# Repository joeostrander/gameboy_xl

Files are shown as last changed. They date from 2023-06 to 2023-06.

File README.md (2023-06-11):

# Gameboy_XL & Gameboy_XL Touch

## Description
A larger, grown-up Gameboy... but it's not a GameMan

2 versions you can make, 1 with a touch screen!

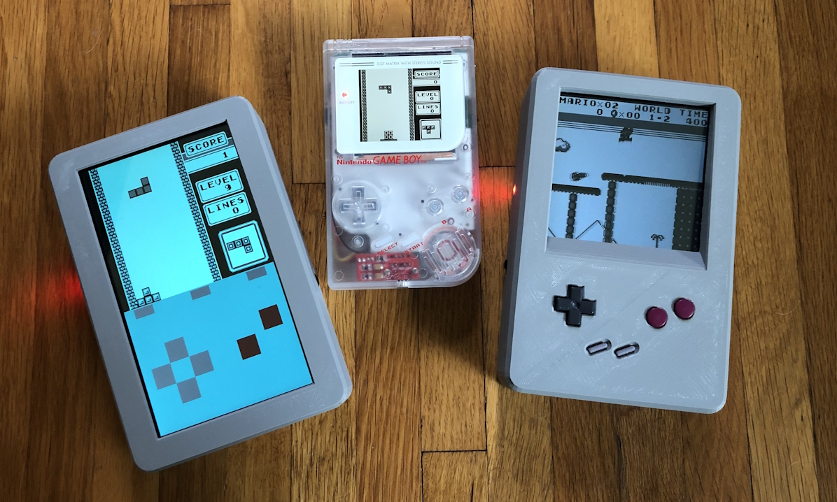
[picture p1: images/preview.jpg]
preview


[Video](https://youtu.be/DkDZt74SX64)

See also:

Gameboy consolizer that me and Andy West collaborated on:
https://github.com/joeostrander/consolized-game-boy

PICO LCD
https://github.com/joeostrander/PICO_LCD

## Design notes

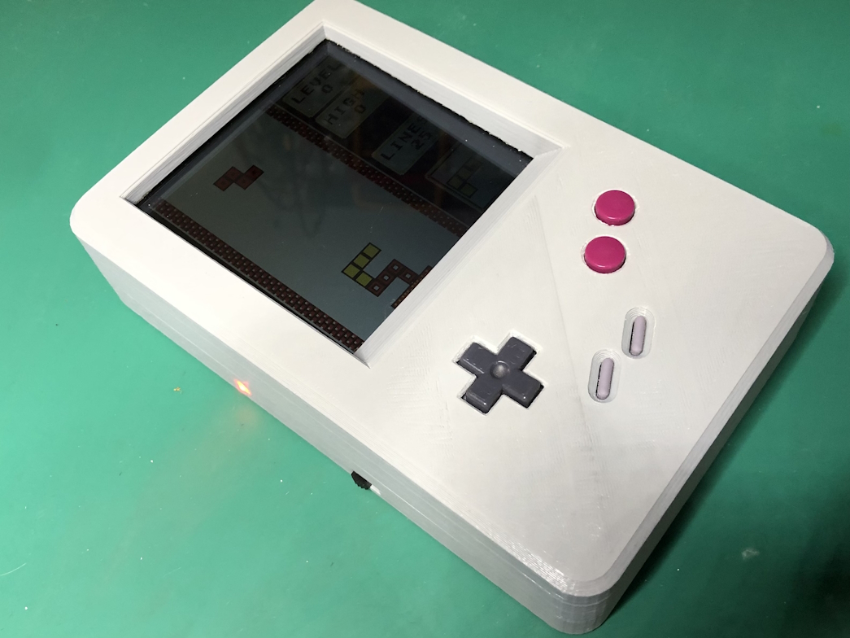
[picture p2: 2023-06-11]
images/IMG_E4839.JPG

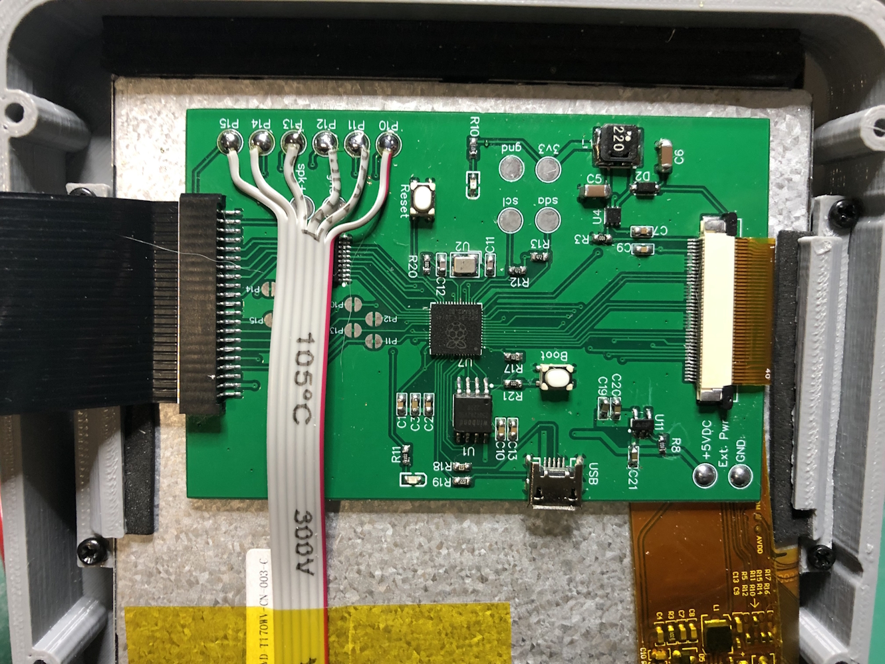
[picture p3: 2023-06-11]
images/IMG_E4575.JPG

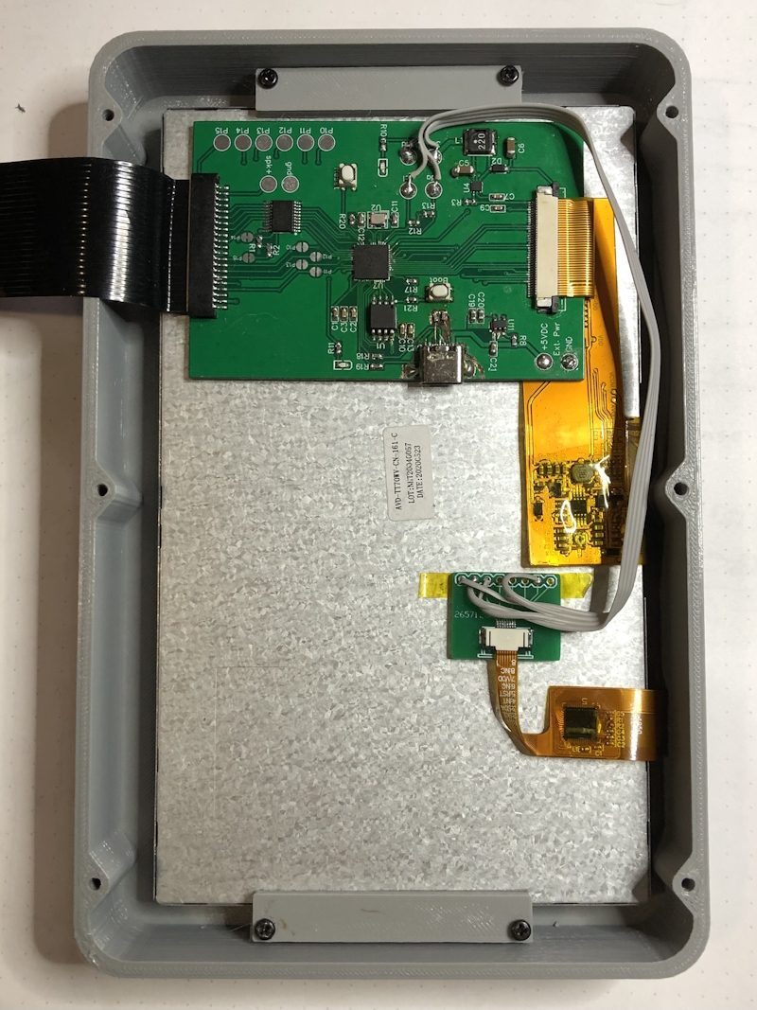
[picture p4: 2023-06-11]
images/touch_lcd_back1.JPG

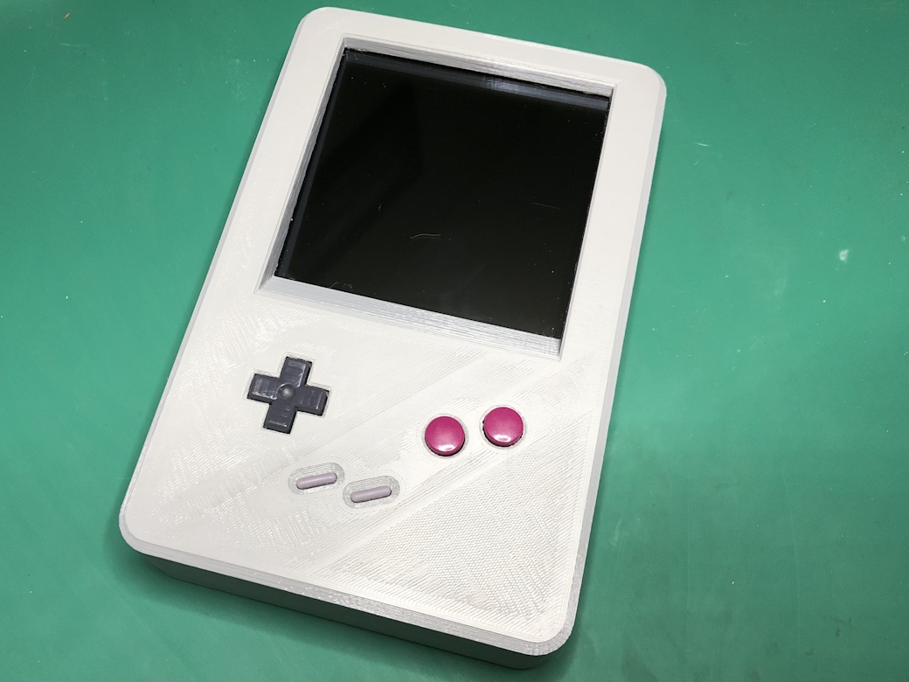
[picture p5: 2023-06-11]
images/IMG_E4836.JPG

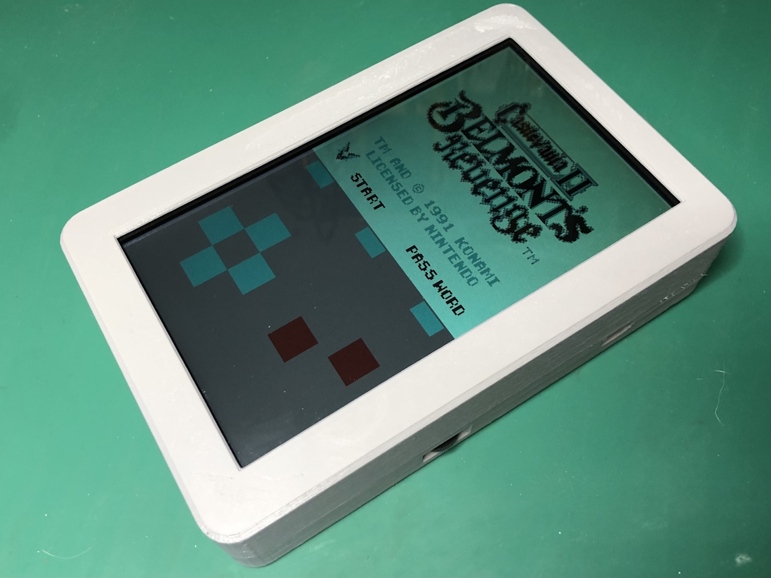
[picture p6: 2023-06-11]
images/touch2.JPG

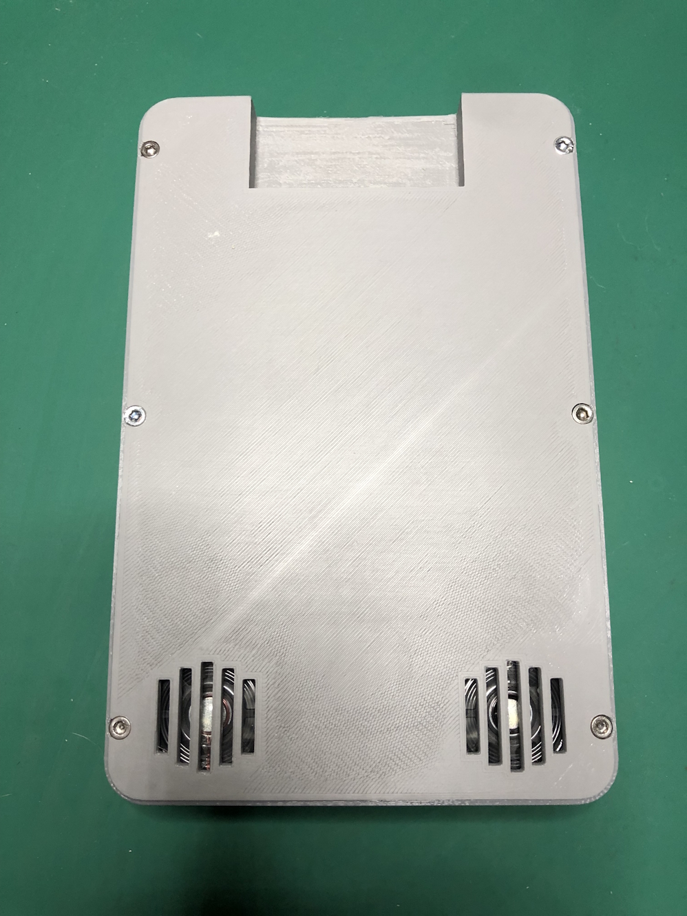
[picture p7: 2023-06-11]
images/touch_case_back.JPG

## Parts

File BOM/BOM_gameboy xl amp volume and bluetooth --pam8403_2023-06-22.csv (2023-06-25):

ID | Name | Designator | Footprint | Quantity | Manufacturer Part | Manufacturer | Supplier | Supplier Part
1 | 0.47uF | C1,C2 | 0603 CAPACITOR | 2 | CAPCERAMIC0.22UF16V20%X5R0201 | null
2 | 0.1uF | C3 | 0603 CAPACITOR | 1 | CAPCERAMIC0.22UF16V20%X5R0201 | null
3 | 10uF | C4 | 0603 CAPACITOR | 1 | CAPCERAMIC0.22UF16V20%X5R0201 | null
4 | 100uF 10V | C5 | CAP-SMD_L3.5-W2.8-R-RD | 1 | T491M107K006AT | KEMET | Digi-Key | 399-11391
5 | LED_BLUE | LED_BLUE | LED_5MM | 1
6 | 20K | R1,R2 | RESISTOR_R0603 | 2
7 | 10R | R3 | RESISTOR_R0603 | 1
8 | 1K | R4 | RESISTOR_R0603 | 1
9 | Button-6x6x9-Right-Angle | SW1 | SW-TH_BBJ | 1 | TL1105RF160Q94VO | E-Switch | Digi-Key | TL1105RF160Q94VO-ND
10 | EG1206A | SW2 | SW-TH_EG1206A | 1 | EG1206A | E-Switch | LCSC | C273392
11 | PAM8403DR_C348830 | U2 | SOP-16_L9.9-W3.9-P1.27-LS6.0-BL | 1 | PAM8403DR-H |  | Digi-Key | PAM8403DR
12 | KCX_BT_EMITTER | U3 | KCX_BT_EMITTER | 1 |  |  | Ali-Express
13 | DMG Volume potentiometer | VR1 | DMG-POT | 1 |  |  | Ali-Express

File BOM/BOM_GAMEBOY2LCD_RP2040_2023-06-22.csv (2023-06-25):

ID | Name | Designator | Footprint | Quantity | Manufacturer Part | Manufacturer | Supplier | Supplier Part
2 | 0.1uF | C1,C2,C7,C9,C13 | 0603 CAPACITOR | 5
3 | 2.2uF | C3,C10 | 0603 CAPACITOR | 2
4 | 10uF | C5,C6 | CAPC3216X180N | 2
5 | 15pF | C11,C12 | 0603 CAPACITOR | 2
6 | 10uF | C19,C20,C21 | 0603 CAPACITOR | 3
7 | MBR0540T1G | D2 | SOD-123_L2.8-W1.8-LS3.7-RD | 1 | MBR0540T1G | ON | LCSC | C21353
9 | 0541044031 V2 | J1 | 541044031 | 1
10 | 22uH | L1 | IND-SMD_L5.0-W5.0_VLCF5020 | 1 | VLCF5020T-220MR75-1 | TDK | LCSC | C87576
11 | TJ-S1608SW6TGLC6B-A5 | LED_BLUE1 | LED0603-R-RD_BLUE | 1 | TJ-S1608SW6TGLC6B-A5 | TOGIALED | LCSC | C192317
12 | TJ-S1608SW6TGLC2R-A5 | LED_RED1 | LED0603-R-RD_RED | 1 | TJ-S1608SW6TGLC2R-A5 | TOGIALED | LCSC | C192315
19 | 10K | R1,R2,R8,R17 | RESISTOR_R0603 | 4
20 | 10R | R3 | RESISTOR_R0603 | 1
21 | 470 | R10 | RESISTOR_R0603 | 1
22 | 1K | R11,R20,R21 | RESISTOR_R0603 | 3
23 | 4.7K | R12,R13 | RESISTOR_R0603 | 2
24 | 27R | R18,R19 | RESISTOR_R0603 | 2
37 | Boot | SW1 | PUSHBUTTON SMD 3X4X2.5 | 1
38 | Reset | SW2 | PUSHBUTTON SMD 3X4X2.5 | 1
39 | W25Q128JVSIQ | U1 | SOIC-8_L5.3-W5.3-P1.27-LS8.0-BL | 1 | W25Q128JVSIQ | WINBOND(??) | LCSC | C113767
40 | FA-238V 12.0000MA-C5 | U2 | CRYSTAL-SMD_4P-L3.2-W2.5-BL | 1 | FA-238V 12.0000MA-C5 | EPSON | LCSC | C1985398
41 | SN74LVC245APWR | U3 | TSSOP-20_L6.5-W4.4-P0.65-LS6.4-BL | 1 | SN74LVC245APWR | TI(Texas Instruments) | LCSC | C7848
42 | TPS61160DRVR | U4 | WSON-6_L2.0-W2.0-P0.65-TL-EP | 1 | TPS61160DRVR | TI(Texas Instruments) | LCSC | C165143
43 | DMG SCREEN CONNECTOR - NO HOLES | U6 | DMG SCREEN CONNECTOR - NO HOLES | 1 |  |  | Ali-Express
44 | RP2040 | U7 | RP2040-QFN56 | 1 | RP2040 | Raspberry Pi |  | C2961140
45 | AP2112K-3.3TRG1 | U11 | SOT-25-5_L3.0-W1.8-P0.95-LS3.0-BR | 1 | AP2112K-3.3TRG1 | DIODES | LCSC | C51118
46 | U-F-M5DD-W-2 | USB | MICRO-USB-SMD_MICRO-USB-A17 | 1 | U-F-M5DD-W-2 | HRO | LCSC | C145793

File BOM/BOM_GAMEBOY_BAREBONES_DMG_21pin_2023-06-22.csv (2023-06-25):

ID | Name | Designator | Footprint | Quantity | Manufacturer Part | Manufacturer | Supplier | Supplier Part
1 | 27pF | C1,C2 | 0603/SMD | 2
2 | 1uF | C3,C4 | CAP-SMD_L3.5-W2.8-R-RD | 2 | T491B105K050AT | KEMET | LCSC | C600503
3 | 1M | R13 | RESISTOR_R0603 | 1
4 | 180K | R14 | RESISTOR_R0603 | 1
5 | 510R | R16,R17 | RESISTOR_R0603 | 2
6 | dmg screen connector | U1 | DMG SCREEN CONNECTOR - NO HOLES | 1 |  |  | Ali-Express
7 | LH5264 Work RAM | U2 | DMG LH5264 | 1 |  |  | Get from a DMG or Super Gameboy cartridge
8 | DMG Cartridge Header PTH | U3 | DMG CARTRIDGE HEADER | 1 |  |  | Get from a DMG
9 | LH5264 Video RAM | U5 | DMG LH5264 | 1 |  |  | Get from a DMG or Super Gameboy cartridge
10 | DMG-CPU-B | U8 | DMG-CPU-B | 1 |  |  | Get from a DMG or Super Gameboy cartridge
11 | ABLS-4.194304MHZ-D-4-Y-T | X2 | CRYSTAL-SMD_L11.4-W4.7-LS12.7 | 1 | ABLS-4.194304MHZ-D-4-Y-T | ABRACON | Digi-Key | 535-14925

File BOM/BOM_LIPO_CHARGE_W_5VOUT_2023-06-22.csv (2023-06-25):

ID | Name | Designator | Footprint | Quantity | Manufacturer Part | Manufacturer | Supplier | Supplier Part
2 | 0.1uF | C4 | 0603 CAPACITOR | 1
3 | 10uF | C8,C14,C18,C21 | 0603 CAPACITOR | 4
4 | 22uF | C15,C16,C17 | CAPACITOR_SMD0805 | 3
5 | 10uF | C22,C23 | CAPACITOR_SMD0805 | 2
6 | S2B-PH-SM4-TB(LF)(SN) | CN1 | CONN-SMD_P2.00_S2B-PH-SM4-TB-LF-SN | 1 | S2B-PH-SM4-TB(LF)(SN) | JST | LCSC | C295747
7 | BAT20JFILM | D3 | SOD-323_L1.8-W1.3-LS2.5-RD | 1 | BAT20JFILM | ST(STMicroelectronics) | LCSC | C155590
10 | 1.5uH | L2 | IND-SMD_L4.0-W4.0 | 1 | XEL4030-152MEC | Coilcraft | Mouser | 994-XEL4030-152MEC
11 | SI2305B-TP | Q2 | SOT-23-3_L2.9-W1.3-P1.90-LS2.4-BR | 1 | SI2305B-TP | MCC(Micro Commercial Components) | LCSC | C668997
12 | 2K | R4 | RESISTOR_R0603 | 1
13 | 10K | R5,R6,R9 | RESISTOR_R0603 | 3
14 | 100K | R7 | RESISTOR_R0603 | 1
15 | TPS630701RNMR | U5 | TPS630701RNMR | 1 | TPS630701RNMR | Texas Instruments | Digi-Key | 296-47298
16 | MCP73831T-2ACI/OT | U8 | SOT-23-5_L3.0-W1.7-P0.95-LS2.8-BR | 1 | MCP73831T-2ACI/OT | MICROCHIP | LCSC | C424093
17 | Led 0603 | U9 | LED 0603 | 1

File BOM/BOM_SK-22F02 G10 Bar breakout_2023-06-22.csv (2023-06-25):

ID | Name | Designator | Footprint | Quantity | Manufacturer Part | Manufacturer | Supplier | Supplier Part | Price
1 | SK-22F02 G10 Bar | SW1 | SK-22F02 G10 BAR | 1 |  |  | Ali-Express
2 | HEADER_2.54_1X3 | U5 | HEADER_2.54_1X3 | 1

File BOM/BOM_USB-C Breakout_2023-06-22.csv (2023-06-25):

ID | Name | Designator | Footprint | Quantity | Manufacturer Part | Manufacturer | Supplier | Supplier Part | Price
1 | 5.1K | R1,R2 | RESISTOR_R0603 | 2
2 | HEADER_2.54_1X4 | U1 | HEADER_2.54_1X4 | 1
3 | USB_C RECEPTACLE - ADAFRUIT | X1 | USB_C_ADAFRUIT_4458 | 1

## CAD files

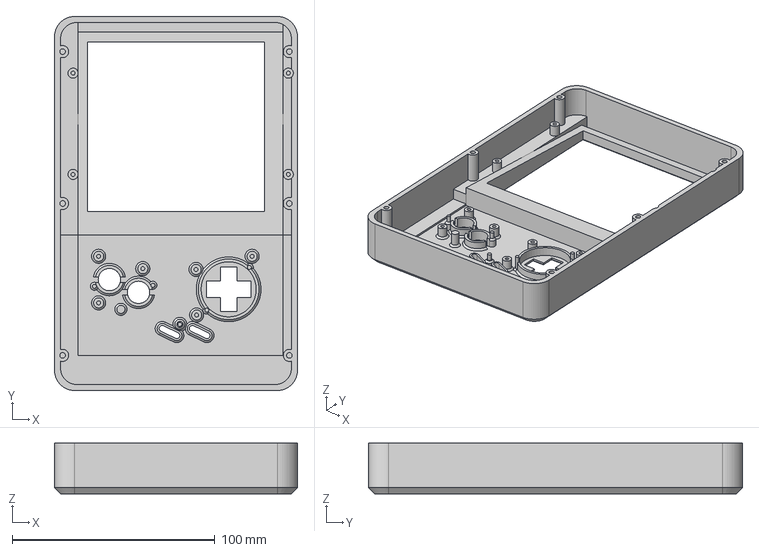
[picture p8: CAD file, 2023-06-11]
3D/non-touch/gameboy_xl_case_top.step
120.0 x 184.7 x 25.0 mm

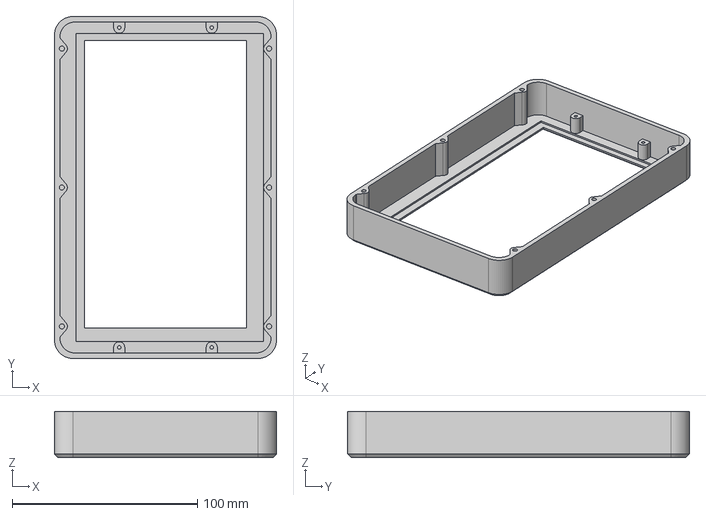
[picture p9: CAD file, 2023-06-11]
3D/touch/gameboy_xl_touch_case_top.step
120.0 x 184.8 x 25.0 mm

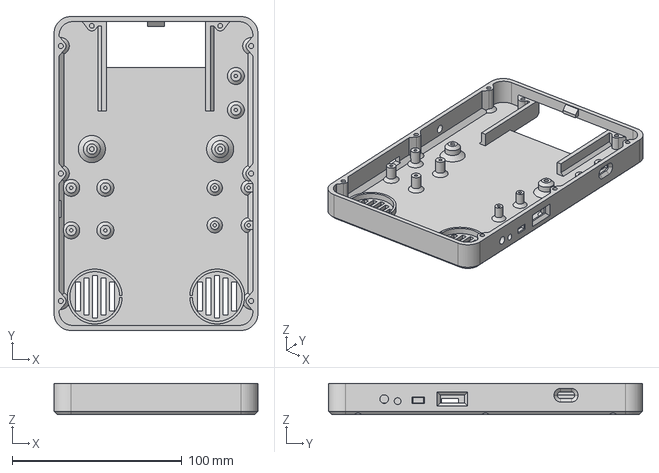
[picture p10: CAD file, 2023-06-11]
3D/non-touch/gameboy_xl_case_bottom.step
120.0 x 184.8 x 18.5 mm

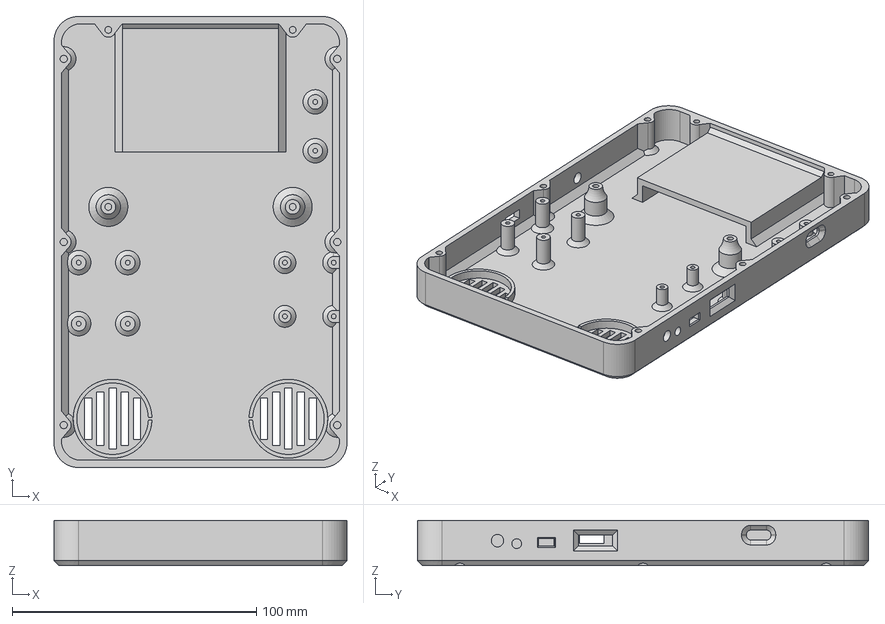
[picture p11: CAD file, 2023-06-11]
3D/touch/gameboy_xl_touch_case_bottom.step
120.0 x 184.8 x 18.5 mm

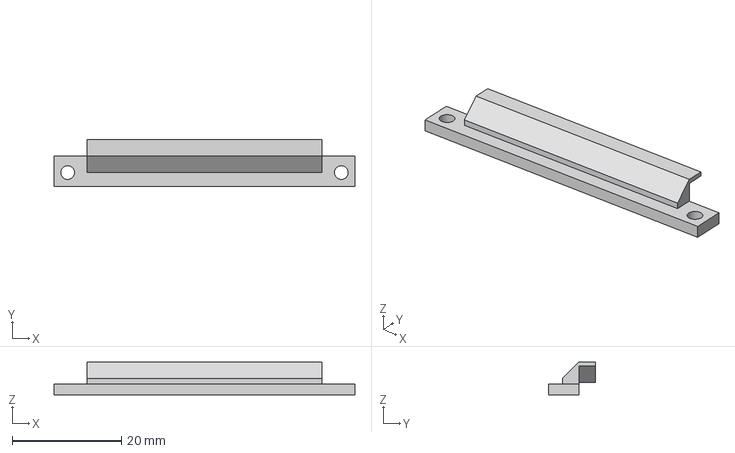
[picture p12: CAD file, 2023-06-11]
3D/non-touch/gameboy_xl_lcd_brace_angled.step
55.0 x 8.50 x 6.00 mm

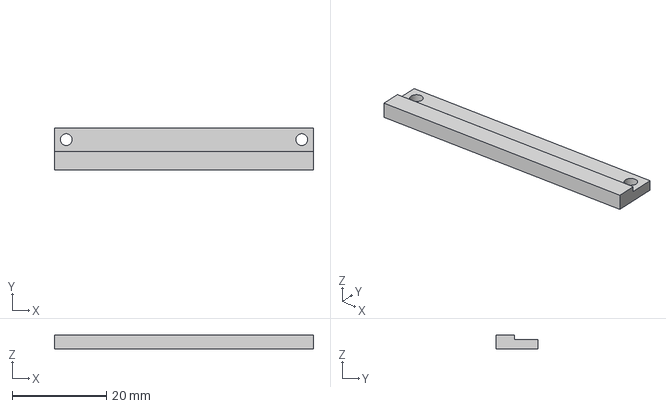
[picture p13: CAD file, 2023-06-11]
3D/touch/gameboy_xl_touch_lcd_brace.step
55.0 x 9.00 x 3.00 mm

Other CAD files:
3D/non-touch/gameboy_xl_case_bottom.stl
3D/non-touch/gameboy_xl_case_top.stl
3D/non-touch/gameboy_xl_lcd_brace_angled.stl
3D/touch/gameboy_xl_touch_case_bottom.stl
3D/touch/gameboy_xl_touch_case_top.stl
3D/touch/gameboy_xl_touch_lcd_brace.stl

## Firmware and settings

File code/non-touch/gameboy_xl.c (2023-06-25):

// Joe Ostrander
// Gameboy XL (non-touch)
// 2023.05.06

// Key differences:
//  all GB P* pins are input
//  no touch driver

// Note about scanvideo:
// When scaling, there is a bug in scanvideo.c that prevents line zero from repeating
// see my fix --> https://github.com/joeostrander/pico-extras/commit/3ed9467f0203acd9bedfdbb08bed8f31b61b320c

#include <stdio.h>
#include <stdlib.h>
#include <string.h> // for memcmp
#include "time.h"
#include "pico.h"
#include "pico/stdlib.h"
#include "pico/multicore.h"
#include "pico/scanvideo.h"
#include "pico/scanvideo/composable_scanline.h"
#include "pico/sync.h"
#include "hardware/vreg.h"
#include "pico/stdio.h"
#include "osd.h"
#include "hardware/pwm.h"
#include "colors.h"


#define MIN_RUN 3

#define ONBOARD_LED_PIN             25
#define LCD_DISP_PIN                10
#define BACKLIGHT_PWM_PIN           11  // PWM_B[5]
#define BACKLIGHT_PWM_MAX           0xFFFF

#define DMG_READING_DPAD_PIN        20      // P14
#define DMG_READING_BUTTONS_PIN     19      // P15
#define DMG_OUTPUT_LEFT_B_PIN       26      // P11
#define DMG_OUTPUT_DOWN_START_PIN   22      // P13
#define DMG_OUTPUT_UP_SELECT_PIN    21      // P12
#define DMG_OUTPUT_RIGHT_A_PIN      27      // P10

// GAMEBOY VIDEO INPUT (From level shifter)
#define VSYNC_PIN                   18
#define PIXEL_CLOCK_PIN             17
#define HSYNC_PIN                   16
#define DATA_0_PIN                  15
#define DATA_1_PIN                  14

// at 3x Game area will be 480x432 
#define DMG_PIXELS_X                160
#define DMG_PIXELS_Y                144
#define DMG_PIXEL_COUNT             (DMG_PIXELS_X*DMG_PIXELS_Y)

typedef enum
{
    BUTTON_A = 0,
    BUTTON_B,
    BUTTON_SELECT,
    BUTTON_START,
    BUTTON_UP,
    BUTTON_DOWN,
    BUTTON_LEFT,
    BUTTON_RIGHT,
    BUTTON_COUNT
} controller_button_t;

typedef enum
{
    OSD_LINE_COLOR_SCHEME = 0,
    OSD_LINE_BACKLIGHT,
    OSD_LINE_EXIT,
    OSD_LINE_COUNT
} osd_line_t;

const scanvideo_timing_t vga_timing_800x480 =
{
        .clock_freq = 24000000,

        .h_active = 800,
        .v_active = 480,

        .h_front_porch = 40,
        .h_pulse = 12,
        .h_total = 960,
        .h_sync_polarity = 1,

        .v_front_porch = 2,
        .v_pulse = 2,
        .v_total = 500, 
        .v_sync_polarity = 1,

        .enable_clock = 1,
        .clock_polarity = 0,

        .enable_den = 0
};

const scanvideo_mode_t vga_mode_tft_800x480_3x_scale =
{
        .default_timing = &vga_timing_800x480,
        .pio_program = &video_24mhz_composable,
        .width = 800,
        .height = 480,
        .xscale = 3,
        .yscale = 3,
};

typedef struct rectangle_t
{
    uint16_t x;
    uint16_t y;
    uint16_t width;
    uint16_t height;
} rectangle_t;

typedef enum
{
    BUTTON_STATE_PRESSED = 0,
    BUTTON_STATE_UNPRESSED
} button_state_t;

#define VGA_MODE        vga_mode_tft_800x480_3x_scale
#define LINE_LENGTH     ((uint16_t)(((VGA_MODE.width * 100.0)/VGA_MODE.xscale) + 50) / 100)

static rectangle_t rect_gamewindow;
static rectangle_t rect_osd;
static uint16_t background_color;
static int backlight_level = 10;    // 1 to 10

static semaphore_t video_initted;
static uint8_t button_states[BUTTON_COUNT];
static uint8_t button_states_previous[BUTTON_COUNT];
static color_scheme_t* color_scheme;
static control_scheme_t* control_scheme;

static uint8_t framebuffer[DMG_PIXEL_COUNT];
static uint8_t* osd_framebuffer = NULL;

static void core1_func(void);
static void render_scanline(scanvideo_scanline_buffer_t *buffer);
static void initialize_gpio(void);
static void gpio_callback(uint gpio, uint32_t events);
static void gpio_callback_VIDEO(uint gpio, uint32_t events);
static bool button_is_pressed(controller_button_t button);
static bool button_was_released(controller_button_t button);
static void __no_inline_not_in_flash_func(command_check)(void);
static void update_osd(void);
static void blink(uint8_t count, uint16_t millis_on, uint16_t millis_off);
static void change_backlight_level(int direction);
static void set_orientation(void);

int32_t single_solid_line(uint32_t *buf, size_t buf_length, uint16_t color);
int32_t single_scanline(uint32_t *buf, size_t buf_length, uint8_t line_index);

int main(void) 
{
    hw_set_bits(&vreg_and_chip_reset_hw->vreg, VREG_AND_CHIP_RESET_VREG_VSEL_BITS);
    sleep_ms(10);

    //set_sys_clock_khz(300000, true);
    set_sys_clock_khz(240000, true);

    // Create a semaphore to be posted when video init is complete.
    sem_init(&video_initted, 0, 1);

    // Launch all the video on core 1.
    multicore_launch_core1(core1_func);

    // Wait for initialization of video to be complete.
    sem_acquire_blocking(&video_initted);

    initialize_gpio();

    // prevent false trigger of OSD on start -- set all previous button states to 1 (unpressed)
    for (int i = 0; i < BUTTON_COUNT; i++)
    {
        button_states[i] = BUTTON_STATE_UNPRESSED;
        button_states_previous[i] = BUTTON_STATE_UNPRESSED;
    }

    set_background_color(COLOR_BLACK);
    background_color = rgb888_to_rgb222(get_background_color());

    color_scheme = get_scheme();
    control_scheme = get_control_scheme();
    
    osd_framebuffer = OSD_get_framebuffer();
    update_osd();

    set_orientation();

    gpio_set_irq_enabled_with_callback(VSYNC_PIN, GPIO_IRQ_EDGE_FALL | GPIO_IRQ_EDGE_RISE, true, &gpio_callback_VIDEO);

    // for (int i = 0; i < sizeof(framebuffer); i++)
    // {
    //     framebuffer[i] = 0;
    // }

    while (true) 
    {
        static uint32_t last_micros = 0;
        uint32_t current_micros = time_us_32();

        if (current_micros - last_micros > 50000)
        {
            last_micros = current_micros;
            command_check();
            //gpio_put(ONBOARD_LED_PIN, button_states[BUTTON_START] == BUTTON_STATE_PRESSED);
            // uint8_t state = 0;
            // for (int i = 0; i < BUTTON_COUNT; i++)
            // {
            //     if (button_states[i] == BUTTON_STATE_PRESSED)
            //     {
            //         state = 1;
            //     }
            // }
            // gpio_put(ONBOARD_LED_PIN, state);
        }
        
        //blink(3, 100, 2000);
    }
}

int32_t single_scanline(uint32_t *buf, size_t buf_length, uint8_t line_index)
{
    uint16_t* p16 = (uint16_t *) buf;
    uint16_t* first_pixel;
    uint16_t pixel_count = 0;


    // GAME WINDOW
    *p16++ = COMPOSABLE_RAW_RUN;
    first_pixel = p16;
    *p16++ = 0; // replaced later - first pixel
    *p16++ = rect_gamewindow.width - MIN_RUN;

    uint8_t *pbuff = &framebuffer[line_index * rect_gamewindow.width];

    uint16_t pos = 0;
    uint16_t x;
    uint16_t i = 0;
    uint16_t color = 0;

    uint16_t idx;
    uint16_t rot_x;
    uint16_t rot_y;
    for (x = 0; x < rect_gamewindow.width; x++)
    {
        if (x == 0 && i == 0)
        {
            *first_pixel = rgb888_to_rgb222( *((uint32_t*)color_scheme + *pbuff) ) ;
        }
        else
        {
            if ( OSD_is_enabled() 
                && (line_index >= rect_osd.y)
                && (line_index <= (rect_osd.y+rect_osd.height))
                && (x >= rect_osd.x)
                && (x <= (rect_osd.x+rect_osd.width)))
            {
                // ROTATE 270
                rot_x = rect_osd.height - 1 - (line_index-rect_osd.y);
                rot_y = x - rect_osd.x;
               
                idx = rot_x + (rot_y * OSD_WIDTH);
                if (osd_framebuffer != NULL && idx < (OSD_WIDTH*OSD_HEIGHT))
                    color = (uint16_t)(osd_framebuffer[idx]);
            }
            else
            {
                color = rgb888_to_rgb222( *((uint32_t*)color_scheme + *pbuff) ) ;
            }

            *p16++ = color; 
        }

        pbuff++;
        pixel_count++;
    }
  
    if (pixel_count*VGA_MODE.xscale < VGA_MODE.width)
    {
        // remaining = 800 - 205*3 = 
        uint16_t remaining = (VGA_MODE.width - (pixel_count*VGA_MODE.xscale))/VGA_MODE.xscale;
        
        //TESTING!!!
        while (remaining % 3 != 0)
        {
            remaining++;
        }

        // RIGHT BORDER
        if (remaining > MIN_RUN)
        {
            *p16++ = COMPOSABLE_COLOR_RUN;
            *p16++ = background_color; 
            *p16++ = remaining - MIN_RUN;
        }
    }

    // black pixel to end line
    *p16++ = COMPOSABLE_RAW_1P;
    *p16++ = 0;

    *p16++ = COMPOSABLE_EOL_ALIGN;  // TODO... how to determine when to do skip align

    return ((uint32_t *) p16) - buf;
}

int32_t single_solid_line(uint32_t *buf, size_t buf_length, uint16_t color)
{
    uint16_t *p16 = (uint16_t *) buf;

    *p16++ = COMPOSABLE_COLOR_RUN;
    *p16++ = color; 
    *p16++ = LINE_LENGTH - MIN_RUN;

    // black pixel to end line
    *p16++ = COMPOSABLE_RAW_1P;
    *p16++ = 0;

    *p16++ = COMPOSABLE_EOL_ALIGN;
    
    return ((uint32_t *) p16) - buf;
}

static void render_scanline(scanvideo_scanline_buffer_t *dest) 
{
    uint32_t *buf = dest->data;
    size_t buf_length = dest->data_max;
    int line_num = scanvideo_scanline_number(dest->scanline_id);
    int line_start = rect_gamewindow.y;
    int line_end = rect_gamewindow.y + rect_gamewindow.height;
    
    if (line_num < line_start || line_num > line_end)
    {
        dest->data_used = single_solid_line(buf, buf_length, background_color);
    }
    else
    {
        dest->data_used = single_scanline(buf, buf_length, (uint8_t)(line_num - rect_gamewindow.y));
    }

    dest->status = SCANLINE_OK;
}

static void core1_func(void) 
{
    
    hard_assert(VGA_MODE.width + 4 <= PICO_SCANVIDEO_MAX_SCANLINE_BUFFER_WORDS * 2);    

    // Initialize video and interrupts on core 1.
    scanvideo_setup(&VGA_MODE);
    scanvideo_timing_enable(true);
    sem_release(&video_initted);

    gpio_set_irq_enabled_with_callback(DMG_READING_DPAD_PIN, GPIO_IRQ_EDGE_FALL | GPIO_IRQ_EDGE_RISE, true, &gpio_callback);
    gpio_set_irq_enabled_with_callback(DMG_READING_BUTTONS_PIN, GPIO_IRQ_EDGE_FALL | GPIO_IRQ_EDGE_RISE, true, &gpio_callback);

    while (true) 
    {
        scanvideo_scanline_buffer_t *scanline_buffer = scanvideo_begin_scanline_generation(true);
        render_scanline(scanline_buffer);
        scanvideo_end_scanline_generation(scanline_buffer);
    }
}

static void initialize_gpio(void)
{    
    //Onboard LED
    gpio_init(ONBOARD_LED_PIN);
    gpio_set_dir(ONBOARD_LED_PIN, GPIO_OUT);
    gpio_put(ONBOARD_LED_PIN, 0);

    // LCD DISP PIN
    gpio_init(LCD_DISP_PIN);
    gpio_set_dir(LCD_DISP_PIN, GPIO_OUT);
    gpio_put(LCD_DISP_PIN, 1);

    // LCD Backlight
    gpio_set_function(BACKLIGHT_PWM_PIN, GPIO_FUNC_PWM);
    uint sliceNum=pwm_gpio_to_slice_num (BACKLIGHT_PWM_PIN); 
    pwm_config config = pwm_get_default_config();
    pwm_init(sliceNum, &config, true);
    change_backlight_level(0);  // 0 - no change

    // Gameboy video signal inputs
    gpio_init(VSYNC_PIN);
    gpio_init(PIXEL_CLOCK_PIN);
    gpio_init(DATA_0_PIN);
    gpio_init(DATA_1_PIN);
    gpio_init(HSYNC_PIN);

    gpio_init(DMG_OUTPUT_RIGHT_A_PIN);
    gpio_set_dir(DMG_OUTPUT_RIGHT_A_PIN, GPIO_IN);

    gpio_init(DMG_OUTPUT_LEFT_B_PIN);
    gpio_set_dir(DMG_OUTPUT_LEFT_B_PIN, GPIO_IN);

    gpio_init(DMG_OUTPUT_UP_SELECT_PIN);
    gpio_set_dir(DMG_OUTPUT_UP_SELECT_PIN, GPIO_IN);

    gpio_init(DMG_OUTPUT_DOWN_START_PIN);
    gpio_set_dir(DMG_OUTPUT_DOWN_START_PIN, GPIO_IN);

    gpio_init(DMG_READING_DPAD_PIN);
    gpio_set_dir(DMG_READING_DPAD_PIN, GPIO_IN);

    gpio_init(DMG_READING_BUTTONS_PIN);
    gpio_set_dir(DMG_READING_BUTTONS_PIN, GPIO_IN);
}

static void gpio_callback(uint gpio, uint32_t events) 
{
    if(gpio==DMG_READING_DPAD_PIN)
    {
        if (events & GPIO_IRQ_EDGE_FALL)   // Read DPAD states on LOW
        {
            button_states[BUTTON_RIGHT] = gpio_get(DMG_OUTPUT_RIGHT_A_PIN);
            button_states[BUTTON_LEFT] = gpio_get(DMG_OUTPUT_LEFT_B_PIN);
            button_states[BUTTON_UP] = gpio_get(DMG_OUTPUT_UP_SELECT_PIN);
            button_states[BUTTON_DOWN] = gpio_get(DMG_OUTPUT_DOWN_START_PIN);
        }
    }

    if(gpio==DMG_READING_BUTTONS_PIN)
    {
        if (events & GPIO_IRQ_EDGE_FALL)   // Read BUTTON states on LOW
        {
            button_states[BUTTON_A] = gpio_get(DMG_OUTPUT_RIGHT_A_PIN);
            button_states[BUTTON_B] = gpio_get(DMG_OUTPUT_LEFT_B_PIN);
            button_states[BUTTON_SELECT] = gpio_get(DMG_OUTPUT_UP_SELECT_PIN);
            button_states[BUTTON_START] = gpio_get(DMG_OUTPUT_DOWN_START_PIN);
        }
    }
}

static bool button_is_pressed(controller_button_t button)
{
    return button_states[button] == BUTTON_STATE_PRESSED;
}

static bool button_was_released(controller_button_t button)
{
    return button_states[button] == BUTTON_STATE_UNPRESSED && button_states_previous[button] == BUTTON_STATE_PRESSED;
}

static void __no_inline_not_in_flash_func(command_check)(void)
{
    if (memcmp(button_states, button_states_previous, sizeof(button_states)) == 0)
        return;

    // Hold Select, release Start for OSD
    if (button_is_pressed(BUTTON_SELECT))
    {
        if (button_was_released(BUTTON_START))
            OSD_toggle();
    }
    else
    {
        if (OSD_is_enabled())
        {
            if (button_was_released(BUTTON_DOWN))
            {
                OSD_change_line(1);
            }
            else if (button_was_released(BUTTON_UP))
            {
                OSD_change_line(-1);
            }
            else if (button_was_released(BUTTON_RIGHT) 
                    || button_was_released(BUTTON_LEFT)
                    || button_was_released(BUTTON_A))
            {
                bool leftbtn = button_was_released(BUTTON_LEFT);
                uint8_t line = OSD_get_active_line();
                if (line == OSD_LINE_COLOR_SCHEME)
                {
                    change_color_scheme_index(leftbtn ? -1 : 1);
                    color_scheme = get_scheme();
                    update_osd();
                }
                else if (line == OSD_LINE_BACKLIGHT)
                {
                    change_backlight_level(leftbtn ? -1 : 1);
                    update_osd();
                }
                else
                {
                    OSD_toggle();
                }
            }
        }
    }

    for (int i = 0; i < BUTTON_COUNT; i++) 
    {
        button_states_previous[i] = button_states[i];
    }
    //OR... memcpy(button_states_previous, button_states, BUTTON_COUNT);
}

static void update_osd(void)
{
    char buff[32];
    sprintf(buff, "COLOR SCHEME:% 5d", get_scheme_index());
    OSD_set_line_text(OSD_LINE_COLOR_SCHEME, buff);

    sprintf(buff, "BACKLIGHT:% 8d", backlight_level);
    OSD_set_line_text(OSD_LINE_BACKLIGHT, buff);

    OSD_set_line_text(OSD_LINE_EXIT, "EXIT");

    OSD_update();
}

static void blink(uint8_t count, uint16_t millis_on, uint16_t millis_off)
{
  static uint8_t blink_count = 0;
  static uint16_t current_rate = 200;
  static uint32_t last_led_change = 0;

  if (count == 0)
  {
    gpio_put(ONBOARD_LED_PIN, 0);
    return;
  }

  uint32_t current_us = time_us_32();
  bool current_state = gpio_get(ONBOARD_LED_PIN);

  bool timeup = (current_us - last_led_change) > (current_rate*1000);
  if (timeup)
  {
    last_led_change = current_us;
    if (current_rate == millis_on)
    {
      bool new_state = !current_state;
      gpio_put(ONBOARD_LED_PIN, new_state);
      if (new_state ==  false)
      {
        blink_count++;
        if (blink_count >= count)
        {
          blink_count = 0;
          current_rate = millis_off;
        }
      }
      return;
    }
    
    blink_count = 0;
    current_rate = millis_on;
  }
}

static void change_backlight_level(int direction)
{
    // level 1 to 10 only
    backlight_level += direction;
    backlight_level = backlight_level < 1 ? 1 : backlight_level > 10 ? 10 : backlight_level;

    uint pwm_value = (uint)(BACKLIGHT_PWM_MAX * backlight_level / 10);
    pwm_set_gpio_level(BACKLIGHT_PWM_PIN, pwm_value);
}

static void set_orientation(void)
{
    rect_gamewindow.x = 0;
    rect_gamewindow.y = 0;
    rect_gamewindow.width = DMG_PIXELS_Y;
    rect_gamewindow.height = DMG_PIXELS_X;
    rect_osd.height = OSD_WIDTH;
    rect_osd.width = OSD_HEIGHT;

    rect_osd.x = (rect_gamewindow.width - rect_osd.width)/2;
    rect_osd.y = (rect_gamewindow.height - rect_osd.height)/2;
}

static void gpio_callback_VIDEO(uint gpio, uint32_t events) 
{
//                  ┌─────────────────────────────────────────┐     
// VSYNC ───────────┘                                         └───────────────────────
//                    ┌──────┐                                     ┌──────┐
// HSYNC ─────────────┘      └─────────────────────────────────────┘      └───────────
//                      ┌─┐     ┌─┐ ┌─┐ ┌─┐ ┌─┐ ┌─┐ ┌─┐ ┌─┐ ┌─┐      ┌─┐     ┌─┐ ┌─┐ ┌
// CLOCK ───────────────┘ └─────┘ └─┘ └─┘ └─┘ └─┘ └─┘ └─┘ └─┘ └──────┘ └─────┘ └─┘ └─┘
//       ─────────────┐   ┌──┐  ┌┐ ┌┐ ┌──┐ ┌┐ ┌┐ ┌───────────────┐   ┌──┐  ┌┐ ┌┐ ┌──┐ 
// DATA 0/1           └───┘  └──┘└─┘└─┘  └─┘└─┘└─┘               └───┘  └──┘└─┘└─┘  └─


    if(gpio==VSYNC_PIN)
    {
        // ignore falling edge interrupt
        if (events & GPIO_IRQ_EDGE_FALL)
            return;
    }

    uint16_t x = 0;
    uint16_t y = 0;
    uint32_t pos = 0;
    uint16_t rot_x = 0;
    uint16_t rot_y = 0;

    for (y = 0; y < DMG_PIXELS_Y; y++)
    {
        // wait for HSYNC edge to fall
        while (gpio_get(HSYNC_PIN) == 0);
        while (gpio_get(HSYNC_PIN) == 1);
        for (x = 0; x < DMG_PIXELS_X; x++)   //DMG_PIXELS_X
        {
            // Rotate 270
            rot_x = y;
            rot_y = rect_gamewindow.height - 1 - x;
            
            pos = rot_x + (rot_y * rect_gamewindow.width);

            if (pos < DMG_PIXEL_COUNT)
                framebuffer[pos] = (gpio_get(DATA_0_PIN) << 1) + gpio_get(DATA_1_PIN);

            // wait for clock pulse to fall
            while (gpio_get(PIXEL_CLOCK_PIN) == 0);
            while (gpio_get(PIXEL_CLOCK_PIN) == 1);
        }
    }
}

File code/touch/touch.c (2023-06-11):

//TODO:  handle touchmove

// touch.c

//*********************************************************************************************
// HEADER FILES
//*********************************************************************************************
#include "touch.h"
#include <string.h> // for memset

//*********************************************************************************************
// CONSTANTS & MACROS
//*********************************************************************************************
#define DRV_I2C_INDEX                           (DRV_I2C_INDEX_1)
#define TOUCH_INTERFACE_TASK_FREQ_HZ            (20)

#define GT911_I2C_SLAVE_ADDRESS                 (0x5D)    // 7-bit address for 0xBA
#define GT911_REG_CONFIG_START                  (0x8047)  // also config version
#define GT911_REG_CONFIG_END                    (0x80FF)  // also config checksum
#define GT911_CONFIG_SIZE                       (GT911_REG_CONFIG_END - GT911_REG_CONFIG_START)
#define GT911_READ_XY_REG                       (0x814E)
#define GT911_STATUS_FLAG_BUFFER_READY          (1<<7)
#define GT911_TOUCH_POINTS_FROM_STATUS(status)  ((status) &= 0xf)
#define GT911_MAX_TOUCH_POINTS                  (5)

#define LCD_WIDTH                               (800)
#define LCD_HEIGHT                              (480)

//*********************************************************************************************
// TYPE DEFINITIONS
//*********************************************************************************************
typedef struct __attribute__((packed))
{
    uint8_t track_id;  // point 1 id = 32, indicates proximity sensing signal
    uint16_t x;
    uint16_t y;
    uint16_t point_size;
    uint8_t reserved;
} touch_point_t;

// typedef struct __attribute__((packed))
// {
//     uint16_t x;
//     uint16_t y;
//     uint16_t point_size;
//     uint8_t reserved;
//     uint8_t track_id;
// } touch_point_t;

typedef struct
{
    uint16_t point_x;
    uint16_t point_y;
    bool valid;
} tracked_touch_t;

// ////
// typedef struct point_data
// {
//     uint8_t status;
//     touch_point_t pd[GT911_MAX_TOUCH_POINTS];
// } point_data_t;
// ////

typedef struct  __attribute__((packed))
{
  uint8_t buffer_status;  //0x814E, Read/Write...  bit 8 = touch present?  low byte = # of touches
  touch_point_t points[GT911_MAX_TOUCH_POINTS];
} operating_data_GT911_t;

// just a taste of the config...
typedef struct __attribute__((packed))
{
    uint8_t version;
    uint16_t x_resolution;
    uint16_t y_resolution;
} config_data_gt911_t;

typedef struct
{
    uint8_t pointCount;
    touch_point_t points[MAX_TOUCH_POINTS];
} TOUCH_DATA_t;

//*********************************************************************************************
// PRIVATE VARIABLES
//*********************************************************************************************
static i2c_inst_t* i2cHandle = NULL;
static tracked_touch_t tracked_touches[MAX_TOUCH_POINTS];
static tracked_touch_t tracked_touches_previous[MAX_TOUCH_POINTS];

//*********************************************************************************************
// PRIVATE FUNCTION PROTOTYPES
//*********************************************************************************************

static void HardwareInit(void);

static bool GetTouchData_GT911(TOUCH_DATA_t *data);

// static bool GetResolution_GT911(leSize *size);
// static bool SetResolution_GT911(void);

static bool GetRegister_GT911(uint16_t registerAddress, uint8_t* read_buffer, uint8_t buffer_length);
static bool ClearStatus_GT911(void);

//static uint8_t Checksum_GT911(uint8_t* bytes,uint8_t length);

static touchDown_FnPtr touchup_callback = NULL;
static touchDown_FnPtr touchdown_callback = NULL;

//*********************************************************************************************
// PUBLIC FUNCTIONS
//*********************************************************************************************
void TOUCH_init(i2c_inst_t* i2c_instance)
{
    i2cHandle = i2c_instance;

    for (int i = 0; i < MAX_TOUCH_POINTS; i++)
    {
        tracked_touches[i].point_x = 0;
        tracked_touches[i].point_y = 0;
        tracked_touches[i].valid = false;
        tracked_touches_previous[i].point_x = 0;
        tracked_touches_previous[i].point_y = 0;
        tracked_touches_previous[i].valid = false;
    }
}

void TOUCH_set_touchup_callback(touchUp_FnPtr cb)
{
    touchup_callback = cb;
}
void TOUCH_set_touchdown_callback(touchDown_FnPtr cb)
{
    touchdown_callback = cb;
}

bool TOUCH_tasks(void)
{
    static uint16_t pos_x = 0;
    static uint16_t pos_y = 0;
    static bool touching = false;
    
    static TOUCH_DATA_t touchData;

    // Initialize the xLastWakeTime variable with the current time.
    //TickType_t xLastWakeTime = xTaskGetTickCount();
    static uint32_t last_poll_micros = 0;
    uint32_t current_micros = time_us_32();

    if (i2cHandle == NULL)
        return false;

    // Initialize the device with the proper I2C address
    //HardwareInit();

    // Need a slight delay to allow the i2c device to fully initialize
    //vTaskDelay(500);
    //sleep_ms(500);

    //TODO(void)SetResolution_GT911();

    // Enter the cyclic portion of the TouchInterface task
    
    if (current_micros - last_poll_micros < 50000)
        return false;

    if( GetTouchData_GT911(&touchData) == true)
    {
        for (int i = 0; i < GT911_MAX_TOUCH_POINTS; i++)
        {
            tracked_touches[i].valid = false;   //reset
            for (int j = 0; j < touchData.pointCount; j++)
            {
                if (touchData.points[j].track_id == i)
                {
                    tracked_touches[i].valid = true;    //TODO:  change valid to touching?
                    tracked_touches[i].point_x = touchData.points[j].x;
                    tracked_touches[i].point_y = touchData.points[j].y;
                }
            }

            if (tracked_touches[i].valid && !tracked_touches_previous[i].valid)
            {
                //touchdown
                if (touchdown_callback != NULL)
                {
                    touchdown_callback(tracked_touches[i].point_x, tracked_touches[i].point_y);
                }
            }
            if (!tracked_touches[i].valid && tracked_touches_previous[i].valid)
            {
                //touchup
                if (touchup_callback != NULL)
                {
                    // send touchup at previous location
                    touchup_callback(tracked_touches_previous[i].point_x, tracked_touches_previous[i].point_y);
                }
            }

            
                 tracked_touches_previous[i].point_x = tracked_touches[i].point_x;
                 tracked_touches_previous[i].point_y = tracked_touches[i].point_y;
                 tracked_touches_previous[i].valid = tracked_touches[i].valid;
        }
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

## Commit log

2023-06-11 add project files
    [gameboy_xl_case_bottom.step, gameboy_xl_case_bottom.stl, gameboy_xl_case_top.step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]
2023-06-11 add bom todo
2023-06-25 - Add EasyEDA exports - remove old V1 board code - BOM files
    [BOM_GAMEBOY2LCD_RP2040_2023-06-22.csv, BOM_GAMEBOY_BAREBONES_DMG_21pin_2023-06-22.csv, BOM_GAMEBOY_BAREBONES_DMG_21pin_SMD_2023-06-22.csv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]
2023-06-26 lipo charge + boost gerber & easyeda update
